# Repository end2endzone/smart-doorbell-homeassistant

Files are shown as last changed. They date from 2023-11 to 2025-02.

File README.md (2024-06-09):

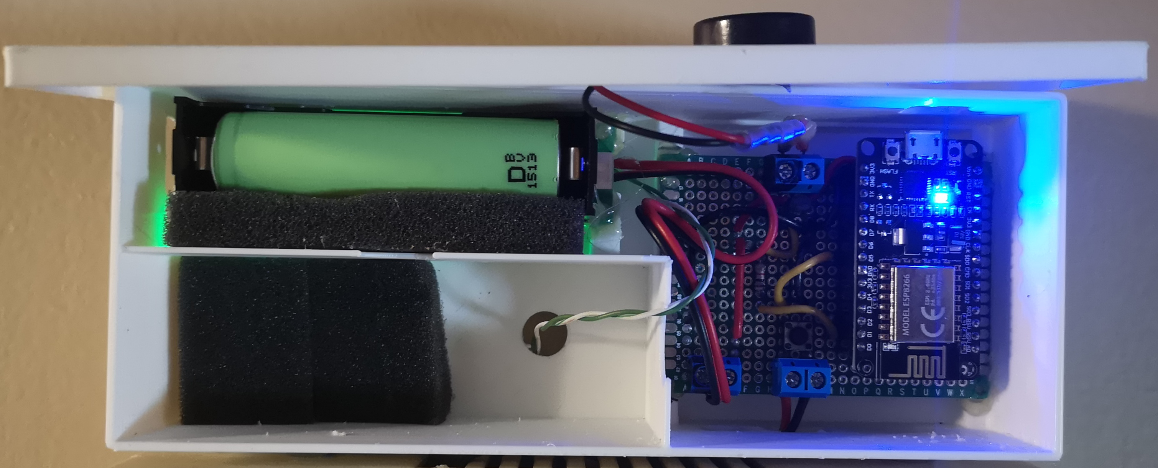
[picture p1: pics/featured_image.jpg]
doorbell logo


# smart-doorbell-homeassistant



A project to convert a traditional electromagnetic chime doorbell into a smart doorbell compatible with Home Assistant.

# Purpose #

I do have a traditional electromagnetic chime doorbell ([how it works](https://home.howstuffworks.com/home-improvement/repair/doorbell3.htm)) already working at my house. We sometimes miss when people ring on the doorbell. It could be because we are downstairs watching a movie. But the chime is also weak and some times, we also miss it when the house is mostly silent. It could also be cultural but where I live, people usually press the button once and wait. I was looking for a solution to this problem.

There are a lot of smart doorbell on the market. Most of them can be easily integrated with smart home softwares. However, most of them requires to be connected to the internet and not subscribtion free. I favor privacy. I wanted to take this opportunity to go DIY and learn from this.

This project allowed me to learn so much new things. I learned to use the [ESP8266 microcontroller](https://en.wikipedia.org/wiki/ESP8266), learned about [MQTT protocol](https://mqtt.org/) and [Home Assistant's MQTT discovery](https://www.home-assistant.io/integrations/mqtt/#mqtt-discovery).

# Features #

The main features of this smart doorbell are:

* Integrates easily with existing hardware.
  * The integration does not alter the original hardware.
  * The doorbell continues to work as usual.
* Audio feedback from an [electric piezo buzzer](https://www.google.com/search?q=piezo+buzzer).
  * Play short [RTTTL melodies](https://www.youtube.com/results?search_query=arduino+rtttl+melodies) when the doorbell rings.
  * User selectable melodies from [a great list of melodies](https://github.com/end2endzone/smart-doorbell-homeassistant/blob/main/src/doorbell/doorbell.ino#L129-L156) or integrate [more melodies](https://github.com/end2endzone/smart-doorbell-homeassistant/blob/main/src/doorbell/rtttl_melodies.txt) or [more ringtones](https://github.com/end2endzone/smart-doorbell-homeassistant/blob/main/src/doorbell/rtttl_ringtones.txt).
  * Play a looping RTTTL melody for device physical location identifier.
* Integrates with [Home Assistant](https://www.home-assistant.io/) through [MQTT protocol](https://mqtt.org/) taking advantage of [Home Assistant's MQTT discovery](https://www.home-assistant.io/integrations/mqtt/#mqtt-discovery) feature.
* Support for multiple devices running simultaneously on the same network.
  * The doorbell identify uniquely on the network using the last 4 digits of its MAC address.
  * Turn all physical doorbell chimes in your house into smart doorbell.
* Support for manual trigger with a physical button or with an "home assistant button" to trigger ringing detection and reporting.

# Requirements #

* A [Home Assistant](https://www.home-assistant.io/) instance.
* An existing [MQTT broker](https://aws.amazon.com/what-is/mqtt/#seo-faq-pairs#what-are-mqtt-comp) service running such as [mosquitto](https://mosquitto.org/).

# Components

The following components are required for the project:

* 1x [50mm x 70mm double sided perfboard](https://www.amazon.ca/s?k=5x7+double+sided+perfboard)
* 1x [ESP8266 microcontroller](https://www.amazon.ca/s?k=ESP8266+NodeMCU+microcontroller)
* 1x [momentary tactile tact push button](https://www.amazon.ca/s?k=Momentary+Tactile+Tact+Push+Button)
* 1x [NPN 2N2222 transistor](https://www.amazon.ca/s?k=NPM+2N2222+transistor)
* 1x [1K Ohm Carbon Film Resistor](https://www.amazon.ca/s?k=1K+Ohm+Carbon+Film+Resistor)
* 3x [2pin screw terminal block connector](https://www.amazon.ca/s?k=2pin+screw+terminal+block+connector)
* 1x [Glass Tube Reed Switch (normally open)](https://www.amazon.ca/s?k=Glass+Tube+Reed+Switch+normally+open)
* 1x [Piezo Electric Buzzer Alarm](https://www.amazon.ca/s?k=Piezo+Electric+Buzzer+Alarm)
* 1x [AC 12V to DC 5V Buck Voltage Regulator Step Down Converter](https://www.amazon.ca/s?k=AC+12V+24V+to+DC+5V+Buck+Voltage+Regulator+Step+Down+Converter)
* 1x [Step Up Module UPS Uninterruptible Power Supply for 18650 Lithium Battery](https://www.amazon.ca/s?k=18650+Lithium+Battery+Boost+Step+Up+Module+UPS+Uninterruptible+Power+Supply)
* 1x [18500 rechargeable li-ion battery](https://www.amazon.ca/s?k=18500+rechargeable+li-ion+battery)

# Circuit Diagram

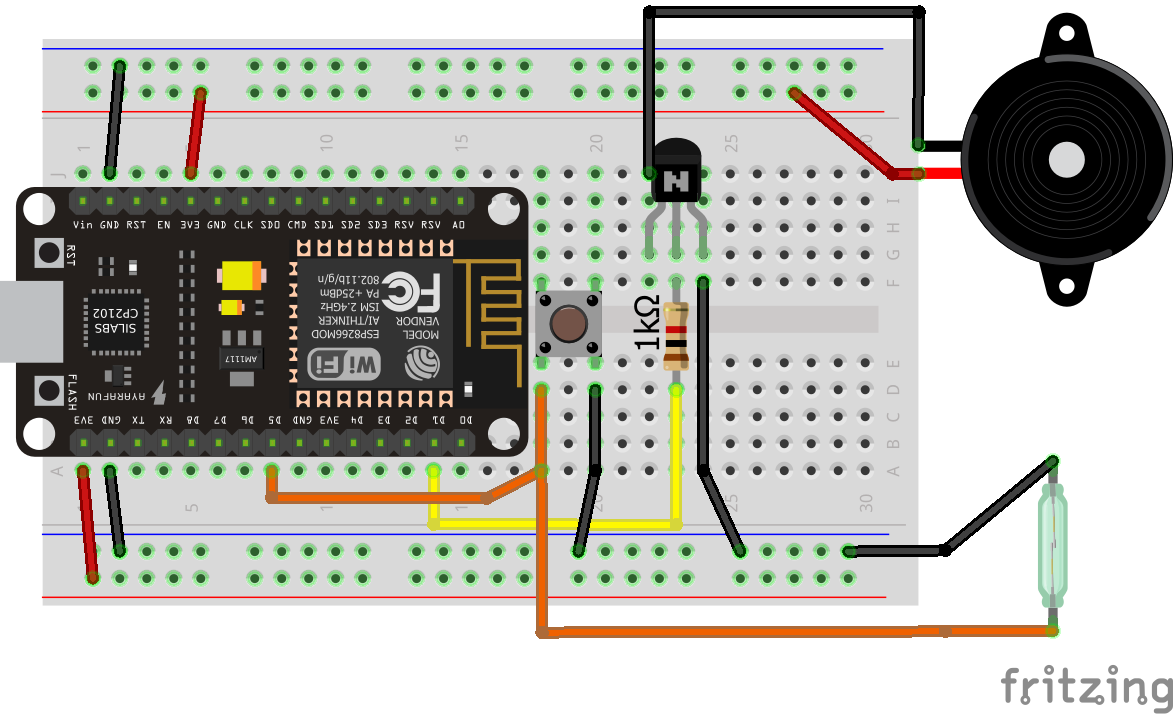
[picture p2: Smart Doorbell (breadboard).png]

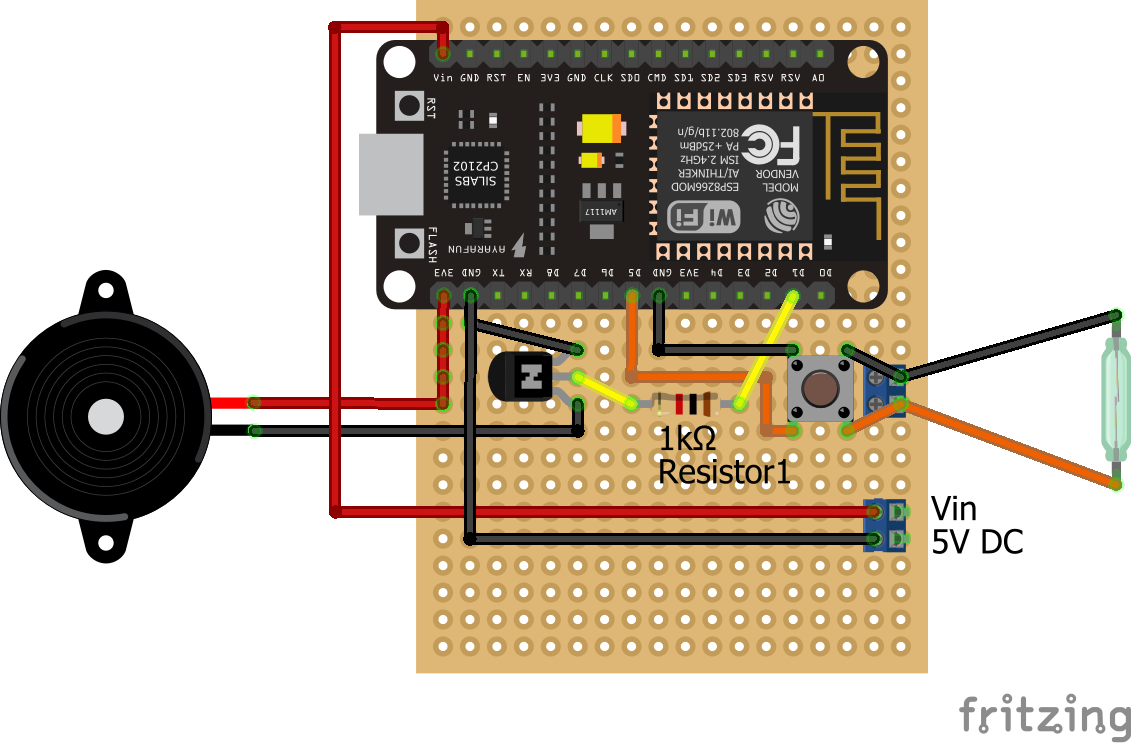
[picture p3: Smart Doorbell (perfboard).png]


# How it works

## Integration with Home Assistant
The device is exposed through [Home Assistant's MQTT discovery](https://www.home-assistant.io/integrations/mqtt/#mqtt-discovery). Home Assistant detects the device automatically and adds it to the dashboard:

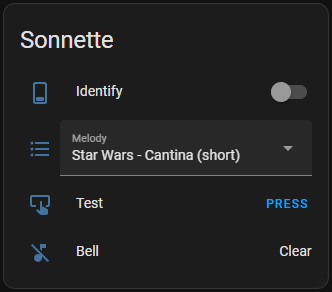
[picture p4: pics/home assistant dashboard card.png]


## Power

The circuit is powered from the existing 12V AC power of the existing doorbell circuitry.

A battery connected to an Uninterruptible Power Supply (UPS) circuit is required when someone rings the doorbell. When ringing, the chime electromagnet is energized temporary cutting the 12V AC power to the step down converter. Without the UPS, the ESP8266 reboots everytime someone rings. The 18650 battery is powering the device when they do.

## Signal detection

When ringing, the chime electromagnet is energized. The electromagnetic field is picked up by the reed switch which trigger an interrupt in the ESP8266. The reed switch is held in place using sticky tack putty.

A tactile push button is connected in parallel to the reed switch to manually trigger the "ringing event" within the microcontroller. 

## MQTT transactions
 
The device is exposed through a single root topic. This topic is formatted as `doorbell-[4-LAST-BYTES-OF-MAC-ADDRESS]`. For example `doorbell-97BC`.

The device outputs its states and commands to the following topics:

| Topics | Value  |
|---|---|
| doorbell-97BC/doorbell/state | OFF |
| doorbell-97BC/identify/state | OFF |
| doorbell-97BC/melody/state | None |
| doorbell-97BC/status | online |
| doorbell-97BC/test/set | OFF |

The device exposes the following entities to _Home Assistant_:
* _binary sensor_, to get the state of the bell ring.
* _switch_, to enable identify mode which plays an audio tone. 
* _select_, to allow user selection of the melody played when the bell is detected.
* _button_, to force the device to report a bell detection for testing purposes.

Each entity names is prefixed with `doorbell-97BC_` allowing unique names.

The required topics to allow the device to be detected by Home Assistant is docummented in [mqtt_discovery_details.md](mqtt_discovery_details.md).

# Pictures

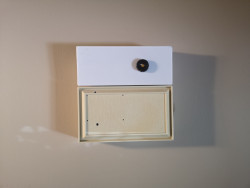
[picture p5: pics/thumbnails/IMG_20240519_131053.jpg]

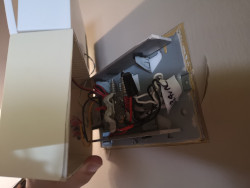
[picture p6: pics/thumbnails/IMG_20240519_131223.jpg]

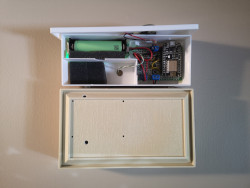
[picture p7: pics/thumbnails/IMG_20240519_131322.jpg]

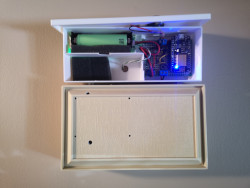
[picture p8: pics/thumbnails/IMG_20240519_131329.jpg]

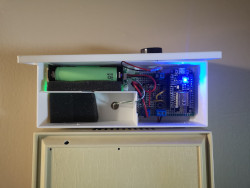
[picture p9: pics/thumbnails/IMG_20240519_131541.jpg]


# Authors #

* **Antoine Beauchamp** - *Initial work* - [end2endzone](https://github.com/end2endzone)

# License #

This project is licensed under the MIT License - see the [LICENSE](LICENSE) file for details

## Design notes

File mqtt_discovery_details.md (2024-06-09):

The following document describes the required MQTT topics for enabling _Home Assistant's MQTT discovery_ feature.

## MQTT transactions
 
The following topics are published to allow the device to be detected by Home Assistant:

**homeassistant/binary_sensor/doorbell-97BC_binary_sensor0/config :**

```json
{
  "device_class": "sound",
  "name": "Bell",
  "unique_id": "doorbell-97BC_binary_sensor0",
  "object_id": "doorbell-97BC_Bell",
  "state_topic": "doorbell-97BC/doorbell/state",
  "availability_topic": "doorbell-97BC/status",
  "payload_available": "online",
  "payload_not_available": "offline",
  "device": {
    "identifiers": [
      "doorbell-97BC"
    ],
    "name": "Smart doorbell 97BC",
    "manufacturer": "end2endzone",
    "model": "ESP8266",
    "hw_version": "1.0",
    "sw_version": "0.1"
  }
}
```

**homeassistant/button/doorbell-97BC_button0/config :**

```json
{
  "name": "Test",
  "unique_id": "doorbell-97BC_button0",
  "object_id": "doorbell-97BC_Test",
  "command_topic": "doorbell-97BC/test/set",
  "state_topic": "doorbell-97BC/test/set",
  "availability_topic": "doorbell-97BC/status",
  "payload_available": "online",
  "payload_not_available": "offline",
  "device": {
    "identifiers": [
      "doorbell-97BC"
    ],
    "name": "Smart doorbell 97BC",
    "manufacturer": "end2endzone",
    "model": "ESP8266",
    "hw_version": "1.0",
    "sw_version": "0.1"
  }
}
```

**homeassistant/select/doorbell-97BC_select0/config :**

```json
{
  "options": [
    "None",
    "Beethoven Fifth Symphony",
    "Coca Cola",
    "Duke Nukem (short)",
    "Entertaine (short)",
    "Flintstones (short)",
    "Intel",
    "Mission Impossible - Intro",
    "Mission Impossible (short)",
    "Mosaic-long",
    "Nokia",
    "Pacman",
    "Popeye (short)",
    "Star Wars - Cantina (short)",
    "Star Wars - Imperial March (short)",
    "Star Wars (short)",
    "Super Mario Bros. 1 (short)",
    "Super Mario Bros. 3 Level 1 (short)",
    "Super Mario Bros. Death",
    "Sweet Child",
    "The Good the Bad and the Ugly (short)",
    "The Itchy Scratchy Show",
    "Tones",
    "Trio",
    "Wolf Whistle",
    "X-Files (short)"
  ],
  "name": "Melody",
  "unique_id": "doorbell-97BC_select0",
  "object_id": "doorbell-97BC_Melody",
  "command_topic": "doorbell-97BC/melody/set",
  "state_topic": "doorbell-97BC/melody/state",
  "availability_topic": "doorbell-97BC/status",
  "payload_available": "online",
  "payload_not_available": "offline",
  "device": {
    "identifiers": [
      "doorbell-97BC"
    ],
    "name": "Smart doorbell 97BC",
    "manufacturer": "end2endzone",
    "model": "ESP8266",
    "hw_version": "1.0",
    "sw_version": "0.1"
  }
}
```

**homeassistant/switch/doorbell-97BC_switch0/config :**

```json
{
  "device_class": "switch",
  "name": "Identify",
  "unique_id": "doorbell-97BC_switch0",
  "object_id": "doorbell-97BC_Identify",
  "command_topic": "doorbell-97BC/identify/set",
  "state_topic": "doorbell-97BC/identify/state",
  "availability_topic": "doorbell-97BC/status",
  "payload_available": "online",
  "payload_not_available": "offline",
  "device": {
    "identifiers": [
      "doorbell-97BC"
    ],
    "name": "Smart doorbell 97BC",
    "manufacturer": "end2endzone",
    "model": "ESP8266",
    "hw_version": "1.0",
    "sw_version": "0.1"
  }
}
```

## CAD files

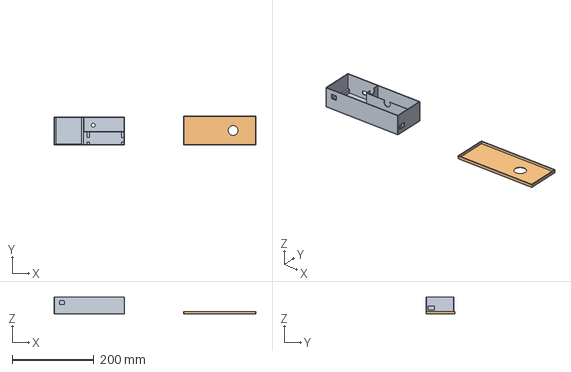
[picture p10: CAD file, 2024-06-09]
3dmodels/doorbell v1.FCStd
494.1 x 72.0 x 41.5 mm
Body-Boitier
Body-Couvert

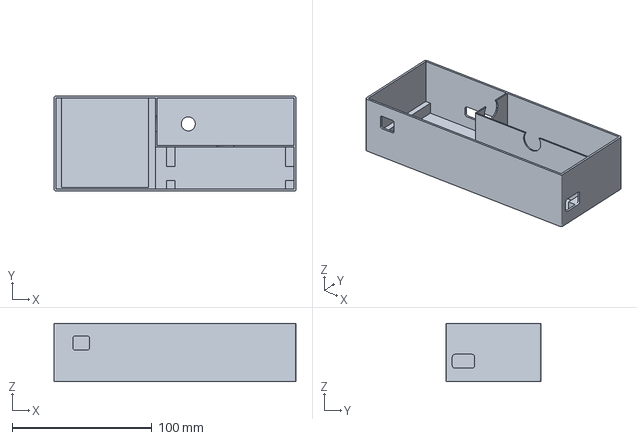
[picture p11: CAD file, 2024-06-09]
3dmodels/case.3mf
173.0 x 68.0 x 41.5 mm

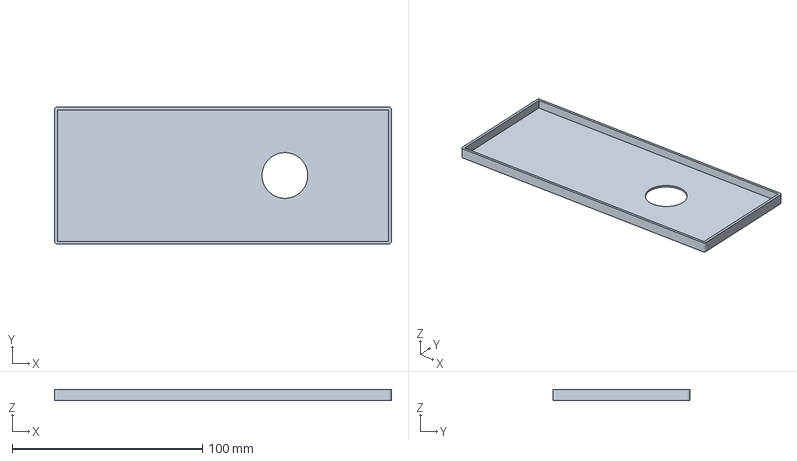
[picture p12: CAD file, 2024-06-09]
3dmodels/cover.3mf
177.0 x 72.0 x 6.00 mm

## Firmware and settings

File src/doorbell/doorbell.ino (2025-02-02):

#include <ESP8266WiFi.h>    // https://github.com/esp8266/Arduino/tree/master/libraries/ESP8266WiFi
#include <PubSubClient.h>   // https://www.arduino.cc/reference/en/libraries/pubsubclient/
#include <SoftTimers.h>     // https://www.arduino.cc/reference/en/libraries/softtimers/
#include <ArduinoJson.h>    // https://www.arduino.cc/reference/en/libraries/arduinojson/
#include <Button.h>         // https://www.arduino.cc/reference/en/libraries/button/
#include <anyrtttl.h>       // https://www.arduino.cc/reference/en/libraries/anyrtttl/
#include <binrtttl.h>       // https://www.arduino.cc/reference/en/libraries/anyrtttl/
#include <pitches.h>        // https://www.arduino.cc/reference/en/libraries/anyrtttl/


#include <strings.h>  // for strcasecmp
#include <cctype>     //for isprint

#include "arduino_secrets.h"

#include "HaMqttDiscovery/HaMqttDiscovery.hpp"
#include "HaMqttDiscovery/HaMqttEntity.hpp"
#include "HaMqttDiscovery/HaMqttDevice.hpp"
#include "HaMqttDiscovery/MqttAdaptorPubSubClient.hpp"

using namespace HaMqttDiscovery;

//************************************************************
//   Constants
//************************************************************

static const char * wifi_ssid = SECRET_WIFI_SSID;
static const char * wifi_pass = SECRET_WIFI_PASS;
static const char* mqtt_user = SECRET_MQTT_USER;
static const char* mqtt_pass = SECRET_MQTT_PASS;

static const uint8_t LED0_PIN = 2;
static const uint8_t LED1_PIN = 16;
static const uint8_t DOORBELL_PIN = D5;
static const uint8_t BUZZER_PIN = D1;

#define ERROR_MESSAGE_PREFIX "*** --> "
#define MAX_PUBLISH_RETRY 5
#define DELAY_BETWEEN_MQTT_TRANSACTIONS 100

//************************************************************
//   Variables
//************************************************************

struct LED_STATE {
  uint8_t pin;
  bool is_on;
  const char * name;
};

struct BELL_SENSOR_STATE {
  bool detected;
};
struct SMART_BELL_SENSOR {
  HaMqttEntity entity;
  BELL_SENSOR_STATE state;
  BELL_SENSOR_STATE previous;
};

struct MELODY_STATE {
  size_t selected_melody;
};
struct SMART_MELODY_SELECTOR {
  HaMqttEntity entity;
  MELODY_STATE state;
};

struct SWITCH_STATE {
  size_t is_on;
};
struct SMART_SWITCH {
  HaMqttEntity entity;
  SWITCH_STATE state;
};

struct BUTTON_STATE {
  size_t is_pressed;
};
struct SMART_BUTTON {
  HaMqttEntity entity;
  BUTTON_STATE state;
  BUTTON_STATE previous;
};

#ifdef SECRET_MQTT_SERVER_HOST
String mqtt_server = SECRET_MQTT_SERVER_HOST;
#else
String mqtt_server = SECRET_MQTT_SERVER_IP;
#endif

WiFiClient wifi_client;
SoftTimer hello_timer; //millisecond timer to show a LED flashing animation when booting.
SoftTimer test_timer; //millisecond timer to force the magnetic ring detection when TEST button is pressed.
SoftTimer online_on_timer; //millisecond timer to define how long the ONLINE led must be ON.
SoftTimer online_off_timer; //millisecond timer to define how long the ONLINE led must be OFF.
SoftTimer activity_off_timer; //millisecond timer to automatically turn off the ACTIVITY led.
SoftTimer doorbell_ring_delay_timer; //millisecond timer, to delay between each doorbell ring
SoftTimer identify_delay_timer; //millisecond timer, to delay between each play of the identify RTTTL melody.
SoftTimer force_publish_timer; //millisecond timer, to force republishing all mqtt data.

static const String device_identifier_prefix = "doorbell";
String device_identifier_postfix;  // matches the last 4 digits of the MAC address
String device_identifier; // defined as device_identifier_prefix followed by device_identifier_postfix

// MQTT support variables
PubSubClient mqtt_client(wifi_client);
MqttAdaptorPubSubClient publish_adaptor;

// Home Assistant support variables
HaMqttDevice this_device;

LED_STATE led_online;
LED_STATE led_activity;
LED_STATE * leds[] = {&led_online, &led_activity};
size_t leds_count = sizeof(leds)/sizeof(leds[0]);

Button bell_sensor_reader(DOORBELL_PIN);
SMART_BELL_SENSOR bell_sensor;

SMART_MELODY_SELECTOR melody_selector;

SMART_BUTTON test_button;

SMART_SWITCH identify;
size_t identify_melody_index = 0;

HaMqttEntity * entities[] = {
  &bell_sensor.entity,
  &melody_selector.entity,
  &test_button.entity,
  &identify.entity,
};
size_t entities_count = sizeof(entities)/sizeof(entities[0]);

HaMqttEntity * subscribable_entities[] = {
  &melody_selector.entity,
  &test_button.entity,
  &identify.entity,
};
size_t subscribable_entities_count = sizeof(subscribable_entities)/sizeof(subscribable_entities[0]);

HaMqttEntity * publishable_entities[] = {
  &bell_sensor.entity,
  &melody_selector.entity,
  &identify.entity,
};
size_t publishable_entities_count = sizeof(publishable_entities)/sizeof(publishable_entities[0]);

static const char* melodies_array[] PROGMEM = {
  "None:d=4,o=5,b=900:32p",
  "Beethoven Fifth Symphony:d=4,o=5,b=125:8p,8g5,8g5,8g5,2d#5",
  "Coca Cola:d=4,o=5,b=125:8f#6,8f#6,8f#6,8f#6,g6,8f#6,e6,8e6,8a6,f#6,d6",
  "Duke Nukem (short):d=4,o=5,b=90:16f#4,16a4,16p,16b4,8p,16f#4,16b4,16p,16c#,8p",
  "Entertaine (short):d=4,o=5,b=140:8d,8d#,8e,c6,8e,c6,8e,2c.6,8c6,8d6,8d#6,8e6,8c6,8d6,e6,8b,d6,2c6",
  "Flintstones (short):d=4,o=5,b=200:g#,c#,8p,c#6,8a#,g#,c#,8p,g#,8f#,8f,8f,8f#,8g#,c#,d#,2f",
  "Intel:d=16,o=5,b=320:d,p,d,p,d,p,g,p,g,p,g,p,d,p,d,p,d,p,a,p,a,p,a,2p,d,p,d,p,d,p,g,p,g,p,g,p,d,p,d,p,d,p,a,p,a,p,a,2p",
  "Mission Impossible - Intro:d=16,o=6,b=95:32d,32d#,32d,32d#,32d,32d#,32d,32d#,32d,32d,32d#,32e,32f,32f#,32g,g",
  "Mission Impossible (short):d=16,o=6,b=95:a#,g,2d,32p,a#,g,2c#,32p,a#,g,2c,a#5,8c,2p,32p,a#5,g5,2f#,32p,a#5,g5,2f,32p,a#5,g5,2e,d#,8d",
  "Mosaic-long:d=8,o=6,b=400:c,e,g,e,c,g,e,g,c,g,c,e,c,g,e,g,e,c,p,c5,e5,g5,e5,c5,g5,e5,g5,c5,g5,c5,e5,c5,g5,e5,g5,e5,c5",
  "Nokia:d=4,o=4,b=180:8e5,8d5,f#,g#,8c#5,8b,d,e,8b,8a,c#,e,2a",
  "Pacman:d=4,o=5,b=112:32b,32p,32b6,32p,32f#6,32p,32d#6,32p,32b6,32f#6,16p,16d#6,16p,32c6,32p,32c7,32p,32g6,32p,32e6,32p,32c7,32g6,16p,16e6,16p,32b,32p,32b6,32p,32f#6,32p,32d#6,32p,32b6,32f#6,16p,16d#6,16p,32d#6,32e6,32f6,32p,32f6,32f#6,32g6,32p,32g6,32g#6,32a6,32p,32b.6",
  "Popeye (short):d=8,o=6,b=160:a5,c,c,c,4a#5,a5,4c",
  "Star Wars - Cantina (short):d=4,o=5,b=250:8a,8p,8d6,8p,8a,8p,8d6,8p,8a,8d6,8p,8a,8p,8g#,a,8a,8g#,8a,g,8f#,8g,8f#,f.,8d.,16p",
  "Star Wars - Imperial March (short):d=4,o=5,b=100:e,e,e,8c,16p,16g,e,8c,16p,16g,e",
  "Star Wars (short):d=4,o=5,b=45:32p,32f#,32f#,32f#,8b.,8f#.6,32e6,32d#6,32c#6,8b.6,16f#.6,32e6,32d#6,32c#6,8b.6,16f#.6,32e6,32d#6,32e6,8c#.6",
  "Super Mario Bros. 1 (short):d=4,o=5,b=100:16e6,16e6,32p,8e6,16c6,8e6,8g6,8p,8g",
  "Super Mario Bros. 3 Level 1 (short):d=4,o=5,b=80:16g,32c,16g.,16a,32c,16a.,16b,32c,16b,16a.,32g#,16a.,16g,32c,16g.,16a,32c,16a,4b.",
  "Super Mario Bros. Death:d=4,o=5,b=90:32c6,32c6,32c6,8p,16b,16f6,16p,16f6,16f.6,16e.6,16d6,16c6,16p,16e,16p,16c",
  "Sweet Child:d=8,o=5,b=140:d,d6,a,g,g6,a,f#6,a,d,d6,a,g,g6,a,8f#6",
  "The Good the Bad and the Ugly (short):d=4,o=5,b=56:32p,32a#,32d#6,32a#,32d#6,8a#.,16f#.,16g#.,d#",
  "The Itchy Scratchy Show:d=4,o=5,b=160:8c6,8a,p,8c6,8a6,p,8c6,8a,8c6,8a,8c6,8a6,p,8p,8c6,8d6,8e6,8p,8e6,8f6,8g6,p,8d6,8c6,d6,8f6,a#6,a6,2c7",
  "Tones:d=8,o=5,b=500:b,16p,b,2p,g,16p,g,2p,d6,16p,d6,2p,d,16p,d.,1p,b,16p,b,2p,g,16p,g,2p,d6,16p,d6,2p,d,16p,d.",
  "Trio:d=32,o=6,b=320:d#,a#5,d#,a#5,d#,a#5,d#,a#5,d#,a#5,d#,p,g,d#,g,d#,g,d#,g,d#,g,d#,g,p,a#,g,a#,g,a#,g,a#,g,a#,g,a#",
  "Wolf Whistle:d=16,o=5,b=900:8a4,a#4,b4,c,c#,d,d#,e,f,f#,g,g#,a,a#,b,c6,8c#6,d6,d#6,e6,f6,4p,4p,a4,a#4,b4,c,c#,d,d#,e,f,f#,g,g#,a,a#,b,a#,a,g#,g,f#,f,e,d#,d,c#,c,b4,a#4,a4",
  "X-Files (short):d=4,o=5,b=125:e,b,a,b,d6,2b.,8p,e,b,a,b,d6,2b.",
};
static const size_t melodies_array_count = sizeof(melodies_array) / sizeof(melodies_array[0]);
static const char* melody_names[melodies_array_count] = {0};
static const size_t INVALID_MELODY_INDEX = (size_t)-1;

/*
class StateChangeNotifyer
{
private:
  int last_state;
  const char * name;
  const char ** states;
  size_t states_count;
  SoftTimer unchanged_timer; //millisecond timer to force printing the actual state if not changed for a while

public:
  StateChangeNotifyer(const char * name, const char** states, size_t states_count) {
    reset();
    this->name = name;
    setStates(states, states_count);
  }
  StateChangeNotifyer(const char * name) {
    reset();
    this->name = name;
  }
  ~StateChangeNotifyer() {}

  void reset() {
    last_state = 0x123456789;
    name = "";
    states == NULL;
    states_count = 0;

    //setup a timer to show existing state if not changed for a while
    unchanged_timer.setTimeOutTime(1000);
    unchanged_timer.reset();
  }

  void setStates(const char** states, size_t states_count) {
    this->states = states;
    this->states_count = states_count;
  }

  const char * getStateName(size_t index) {
    // Get the name of the state
    const char * state_name = "ERROR_UNKNOWN";
    if (index < states_count) {
      state_name = states[index];
    }
    return state_name;
  }

  void update(int new_state) {
    if (new_state != last_state) {
      // State changed

      // Get the name of the state
      size_t state_name_index = (size_t)new_state;
      const char * state_name = getStateName(state_name_index);

      // Output new change
      Serial.println(String() + "New state: " + name + "=" + state_name);

      // reset timer
      unchanged_timer.reset();
    }
    else {
      // state is unchanged
      if (unchanged_timer.hasTimedOut()) {
        // for too long now

        // Get the name of the state
        size_t state_name_index = (size_t)new_state;
        const char * state_name = getStateName(state_name_index);

        // Output existing change
        Serial.println(String() + name + "=" + state_name + " (still)");

        // reset timer
        unchanged_timer.reset();
      }
    }

    last_state = new_state;
  }
};
const char * connection_states[] = {"disconnected", "connected"};
StateChangeNotifyer connection_debugger("connection", connection_states, 2);
*/

class ScopeDebugger
{
private:
  String name;

public:
  ScopeDebugger(const char * name) {
    this->name = name;

    // Print scope enter message
    String msg;
    msg += "<";
    msg += name;
    msg += ">";
    Serial.println(msg);
  }
  ~ScopeDebugger() {
    if (name.isEmpty())
      return;

    // Print scope leave message
    String msg;
    msg += "</";
    msg += name;
    msg += ">";
    Serial.println(msg);
  }
};

//************************************************************
//   Predeclarations
//************************************************************

void setup();
void setup_melody_names();
void setup_wifi();
void setup_device();
void setup_mqtt();
void play_hello_animation();
void led_turn_on(size_t led_index);
void led_turn_off(size_t led_index);
void led_turn_on(LED_STATE * led);
void led_turn_off(LED_STATE * led);
bool is_digit(const char c);
bool is_ip_address(const char * value);
String ip_to_string(const ip_addr_t * ipaddr);
size_t print_cstr_without_terminating_null(const char* str, size_t length, size_t max_chunk_size);
bool is_publishable(HaMqttEntity & test_entity);
bool is_subscribable(HaMqttEntity & test_entity);
void mqtt_subscription_callback(const char* topic, const byte* payload, unsigned int length);
void mqtt_reconnect();
void mqtt_publish_entities_dirty_state(size_t max = -1);
void mqtt_publish_entities_discovery();
void mqtt_force_publish_entities_state();
void mqtt_subscribe_all_entities();
bool parse_boolean(const char * value);
uint8_t parse_uint8(const char * value);
String parse_string_without_terminating_null(const uint8_t * buffer, size_t length);
size_t find_melody_by_name(const char * name);
size_t find_melody_by_name(const String & name);
size_t find_melody_by_name(const uint8_t * buffer, size_t length);
void extract_melody_name(const __FlashStringHelper* str, String & name);
void extract_melody_name(size_t index, String & name);
void increase_mqtt_buffer(uint16_t new_buffer_size = 0);
void timer_force_timed_out(SoftTimer & timer);
String get_pretty_compilation_date();

//************************************************************
//   Function definitions
//************************************************************

void play_hello_animation() {
  digitalWrite(LED0_PIN, HIGH); // OFF
  digitalWrite(LED1_PIN, HIGH); // OFF

  hello_timer.setTimeOutTime(500);
  hello_timer.reset();

  static const int ANIMATION_COUNT = 4;
  for(int i=0; i<ANIMATION_COUNT; i++) {
    int hello_pin = (i%2 == 0 ? LED0_PIN : LED1_PIN);
    hello_timer.reset();  //start counting now

    while(!hello_timer.hasTimedOut()) {
      digitalWrite(hello_pin, LOW); // ON
      delay(50);
      digitalWrite(hello_pin, HIGH); // OFF
      delay(50);
    }
    delay(500);
  }
}

void led_turn_on(size_t led_index) {
  LED_STATE & led = *(leds[led_index]);
  led_turn_on(&led);
}

void led_turn_off(size_t led_index) {
  LED_STATE & led = *(leds[led_index]);
  led_turn_off(&led);
}

void led_turn_on(LED_STATE * led) {
  // Turn the LED on (Note that LOW is the voltage level
  // but actually the LED is on; this is because
  // it is active low on the ESP-01)
  digitalWrite(led->pin, LOW); // ON
  led->is_on = true;
}

void led_turn_off(LED_STATE * led) {
  // Turn the LED off by making the voltage HIGH
  digitalWrite(led->pin, HIGH); // OFF
  led->is_on = false;
}

bool is_digit(const char c) {
  if (c >= '0' && c <= '9')
    return true;
  return false;
}

bool is_ip_address(const char * value) {
  if (value == NULL) return false;
  while(*value != '\0') {
    bool valid = (*value == '.' || is_digit(*value));
    if (!valid)
      return false;
    value++;
  }
  return true;
}

String ip_to_string(const ip_addr_t * ipaddr) {
  if (ipaddr == NULL) return String("INVALID");

  IPAddress tmp;
  tmp = ipaddr->addr;
  return tmp.toString();
}

void setup_melody_names() {
  for(size_t i=0; i<melodies_array_count; i++) {
    // Find the name of this rtttl melody
    String name;
    extract_melody_name(i, name);

    Serial.print("Found melody ");
    Serial.print(String(i));
    Serial.print(": ");
    Serial.println(name);

    melody_names[i] = strdup(name.c_str());
  }

  // Find our IDENTIFY RTTL melody by name
  identify_melody_index = find_melody_by_name("Trio");
  if (identify_melody_index == INVALID_MELODY_INDEX)
    identify_melody_index = 1;
}

void setup_wifi() {
  delay(10);

  // Connecting to local WiFi network
  Serial.println();
  Serial.print("Connecting to ");
  Serial.println(wifi_ssid);

  WiFi.mode(WIFI_STA);
  WiFi.begin(wifi_ssid, wifi_pass);

  while (WiFi.status() != WL_CONNECTED) {
    delay(521); // 521 is a good prime number
    Serial.print(".");
  }

  Serial.println();
  Serial.println("WiFi connected");
  Serial.print("MAC address: ");
  Serial.println(WiFi.macAddress());
  Serial.print("IP address: ");
  Serial.println(WiFi.localIP());
  
  // Print registered DNS server IP addresses.
  for(uint8_t i=0; i<=1; i++) {
    const ip_addr_t* dns_server = dns_getserver(i);
    if (dns_server) {
      String dns_ip = ip_to_string(dns_server);
      Serial.println("DNS " + String(i) + " server IP address is set to " + dns_ip + ".");
    }
    
    // Only print an error message when getting DNS 0
    if (dns_server == NULL && i == 0) {
      Serial.println("Failed to get DNS " + String(i) + " server address. No DNS server is set!");
    }
  }
  
  // init random number generator
  randomSeed(micros());
}
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
void loop() {
  // Should we debug the connection status?
  //connection_debugger.update((int)mqtt_client.connected());

  // make sure mqtt is working
  if (!mqtt_client.connected()) {
    yield();
    mqtt_reconnect();
  }
  mqtt_client.loop();

  // It is time to force publishing all entities again?
  if (force_publish_timer.hasTimedOut()) {
    mqtt_force_publish_entities_state();
    force_publish_timer.reset(); //start counting now
  }

  // Process the ONLINE led blink update.
  // Should the ONLINE led turn off?
  if (led_online.is_on && online_on_timer.hasTimedOut()) {
    led_turn_off(&led_online);
    online_off_timer.reset();  //start counting now
  }
  // Should the ONLINE led turn on?
  if (!led_online.is_on && online_off_timer.hasTimedOut()) {
    led_turn_on(&led_online);
    online_on_timer.reset();  //start counting now
  }

  // Did we waited long enough between each detection?
  // This prevents sending multiple signals to Home Assistant when one repeatedly press the doorbell.
  bool allow_new_ring_detections = false;
  if (doorbell_ring_delay_timer.hasTimedOut()) {
    allow_new_ring_detections = true;
  }

  // Read DOORBELL magnetic field from pin
  bool magnetic_ring_detected = false;
  if (bell_sensor_reader.toggled()) {
    if (bell_sensor_reader.read() == Button::PRESSED && allow_new_ring_detections) {
      bell_sensor.state.detected = true;
    } else {
      bell_sensor.state.detected = false;
    }

    // Only update the MQTT state if the boolean state has actually transitioned.
    if (bell_sensor.previous.detected != bell_sensor.state.detected) {
      bell_sensor.entity.setState(bell_sensor.state.detected ? "ON" : "OFF");
    }
  }

  // Did we pressed the TEST button?
  if (test_button.previous.is_pressed == false && test_button.state.is_pressed && allow_new_ring_detections) {
    // Force the state of the bell sensor to ON
    bell_sensor.state.detected = true;
    bell_sensor.entity.setState(bell_sensor.state.detected ? "ON" : "OFF");

    // Start a timer to stop overriding the bell sensor
    test_timer.reset();
  }
  if (test_button.state.is_pressed && test_timer.hasTimedOut()) {
    // Force the state of the bell sensor to OFF
    bell_sensor.state.detected = false;

    // Only update the MQTT state if the boolean state has actually transitioned.
    if (bell_sensor.previous.detected != bell_sensor.state.detected) {
      bell_sensor.entity.setState(bell_sensor.state.detected ? "ON" : "OFF");
    }

    test_button.state.is_pressed = false;
  }

  // Did we detected new ACTIVITY during this pass?
  if (bell_sensor.state.detected && bell_sensor.entity.getState().isDirty()) {
    doorbell_ring_delay_timer.reset();  //start counting now to know when is the next time allowed to trigger a ring.

    // Turn the ACTIVITY led on
    led_turn_on(&led_activity);
    activity_off_timer.reset(); //start counting now
  }

  // Should we turn off the ACTIVITY led status?
  if (led_activity.is_on && activity_off_timer.hasTimedOut()) {
    led_turn_off(&led_activity);
  }

  // Should we start a doorbell melody?
  if (bell_sensor.state.detected && // do not trigger a melody when button is released 
      bell_sensor.entity.getState().isDirty() &&
      melody_selector.state.selected_melody < melodies_array_count &&
      !anyrtttl::nonblocking::isPlaying())
  {
    const char * selected_melody_buffer = melodies_array[melody_selector.state.selected_melody];
    Serial.print("Playing: ");
    Serial.println(melody_names[melody_selector.state.selected_melody]);
    anyrtttl::nonblocking::begin_P(BUZZER_PIN, selected_melody_buffer);

    // Update our timer
    doorbell_ring_delay_timer.reset();  //start counting now
  }

  // Should we start the identify melody?
  if (identify.state.is_on &&
      identify_melody_index != INVALID_MELODY_INDEX &&
      identify_delay_timer.hasTimedOut() &&
      !anyrtttl::nonblocking::isPlaying())
  {
    const char * melody_buffer = melodies_array[identify_melody_index];
    Serial.print("Playing: ");
    Serial.println(melody_names[identify_melody_index]);
    anyrtttl::nonblocking::begin_P(BUZZER_PIN, melody_buffer);

    // Update our timer
    identify_delay_timer.reset();  //start counting now
  }

  // If we are playing something, keep playing! 
  if ( anyrtttl::nonblocking::isPlaying() )
  {
    anyrtttl::nonblocking::play();
  }

  // Publish a maximum of 1 dirty entity per loop.
  mqtt_publish_entities_dirty_state(1);

  // Remember previous states
  test_button.previous = test_button.state; 
  bell_sensor.previous = bell_sensor.state;
}

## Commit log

2023-07-22 First draft version. The code exposes the ESP8266 LED as a LIGHT to Home Assistant
2023-07-22 Updated code to support two LEDs on ESP8266 board.
2023-07-22 Updated application to use an array of LEDs instead of duplicating all variables.
2023-07-29 Implemented MQTT Last Will and Testament support so that device (and all its entities) becomes "offline" (not available) when the device is disconnected.
2023-07-31 Implemented a button to simulate doorbell ringing. The button is mapped to a Home Assistant entity.
2023-08-08 Shorten all RTTTL melodies and also added "ringtones".
    [doorbell.ino]
2023-08-08 Created an "Identify" button for the device which plays "Trio" RTTTL melody. Retry up to 5 times a failed published. This is required if the payload gets unexpectedly tool large for the buffer.
    [doorbell.ino]
2023-08-09 Converted the "identify button" to a "test button".
2023-08-10 - Implemented a button entity that emulates the detection of the bell sensor. - Renamed `doorbell` variable to `bell_sensor`. - Renamed name of doorbell entity from "BELL" to "Bell". - Renamed the fl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
2023-08-10 Implemented a small delay between each MQTT publishing. This is to try to solve a problem with Home Assistant which do not always detect the device as 'available'.
    [doorbell.ino]
2023-09-04 First version of doorbell circuit in breadboard.
    [Smart Doorbell (breadboard).fzz]
2023-09-04 Added circuit diagram in perfboard version.
    [Smart Doorbell (prefboard).fzz]
2023-09-06 Simplified design of circuit board.
    [Smart Doorbell (prefboard).fzz]
2023-09-06 Moved constants to the top of the sketch. Added a play_hello_animation() function called during setup to show when the board is re/booting.
2023-09-09 Fixed an invalid wire.
    [Smart Doorbell (prefboard).fzz]
2023-09-10 Modified device unique identifier prefix to "doorbell-XXXX" where XXXX is the last 4 digits of the MAC address. Modified auto generated unique_id postfix where the 6th entity of the device was previo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
2023-11-23 Removed "Mini-360 DC-DC Buck converter" from the design in favor to a "AC12V/24V to DC5V Buck Voltage Regulator Waterproof Power Module for Car Step Down Converter (3A)" which directly supply 5V.
    [Smart Doorbell (breadboard).fzz, Smart Doorbell (prefboard).fzz]
2023-11-23 Removed LED-0 and LED-1 "lights" from Doorbell device. LED-0 is now used to show/debug the "mqtt online state". This state is not published to MQTT. LED-1 is now used to show the "activity detected s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
    [doorbell.ino]
2023-11-23 Changed the name of some timers for more clarity.
2023-11-23 Modified how long the ONLINE and the ACTIVITY leds are turned on.
2023-11-23 Fixed a bug where the payload of topic "doorbell-97BC/doorbell/state" was set to "OFF" when already OFF which created unnecessary MQTT transactions.
    [doorbell.ino]
2024-06-09 Added 3d models to repository
    [case.3mf, cover.3mf, doorbell v1.FCStd]
2024-06-09 Fixed typo.
    [Smart Doorbell (perfboard).fzz]
2024-06-14 Using compilation date as device version.
2024-06-14 - Add a timer which refreshes every entity states every 5 min.
2024-06-14 Created publishable and subscribable lists of entities to prevent publishing/subscribing to entities that we dont want to. Also created is_publishable() and is_subscribable() functions.
    [doorbell.ino]
2024-06-16 Revert "Added code that waits to see home assistant's status update while reconnecting."
    This reverts commit 055be8d80f03b48d846c274508ed75f78511d7dc.
    [doorbell.ino]
2024-06-16 Removed double calls to `this_device.publishMqttDeviceStatus()`. Implemented a ScopeDebugger class to debug the enter and exit of each important functions. Protected calls to increase_mqtt_buffer() w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
    [doorbell.ino]
2024-06-18 Added function `get_pretty_compilation_date()` tn convert arduino `__DATE__` macro to a date string in format `yyyy-mm-dd`.

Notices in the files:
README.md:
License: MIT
